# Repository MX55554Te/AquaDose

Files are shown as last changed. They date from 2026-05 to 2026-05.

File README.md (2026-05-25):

# AquaDose Release

AquaDose is an ESP32-based aquarium dosing controller with a native Android app and a local web interface. It controls up to 8 calibrated peristaltic pumps through external MOSFET driver circuits.

Open [README.html](README.html) in a browser for the full styled guide with screenshots, wiring notes, firmware instructions, Android app flow, troubleshooting, and safety notes. GitHub does not render Bootstrap HTML as a normal README page, so this markdown file is intentionally short.

# AquaDose wiring diagram

The simplified wiring diagram below shows the external MOSFET driver circuit used to control the peristaltic pumps from the ESP32.

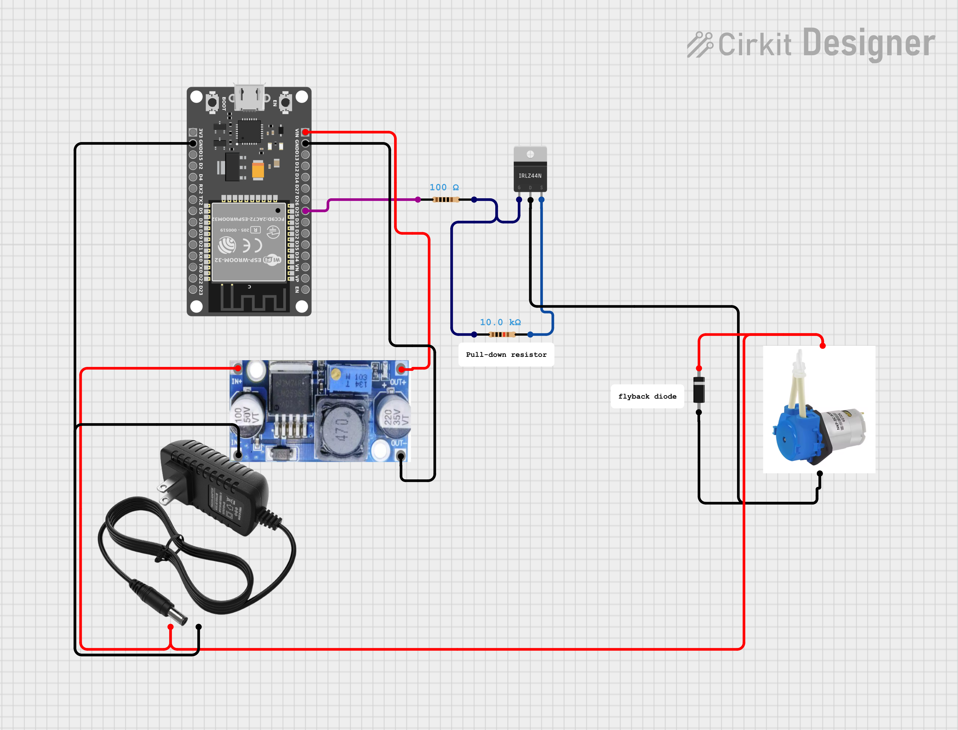
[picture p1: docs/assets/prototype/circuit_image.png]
AquaDose wiring diagram


## Prototype Photos

These photos show the current AquaDose prototype build, including the controller, wiring, pump layout, and enclosure progress.

<table>
  <tr>
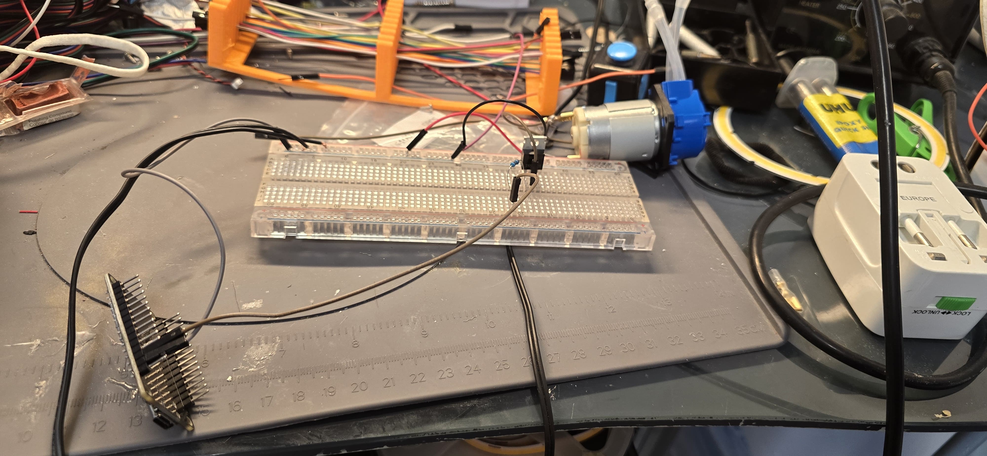
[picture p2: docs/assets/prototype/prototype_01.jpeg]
AquaDose prototype photo 1
    <td></td>
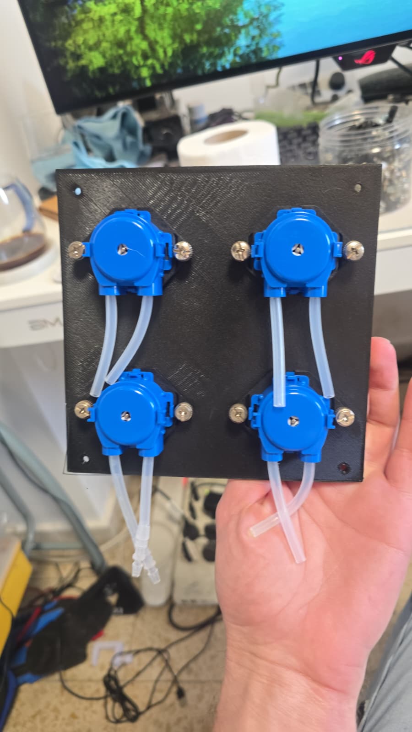
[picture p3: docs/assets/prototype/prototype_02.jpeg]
AquaDose prototype photo 2
    <td></td>
  <tr>
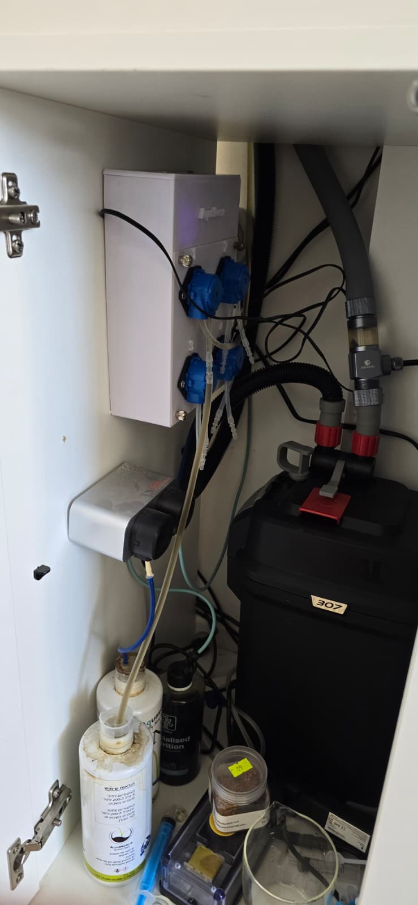
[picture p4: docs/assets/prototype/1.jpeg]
AquaDose prototype photo 1
    <td></td>
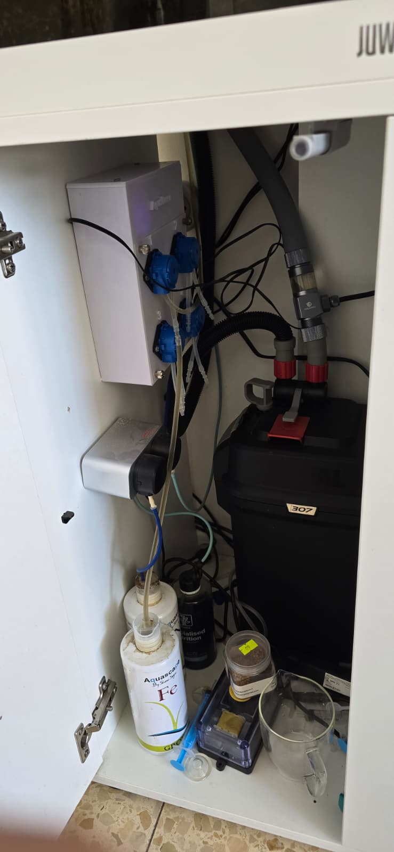
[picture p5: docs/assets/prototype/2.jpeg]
AquaDose prototype photo 2
    <td></td>
  <tr>
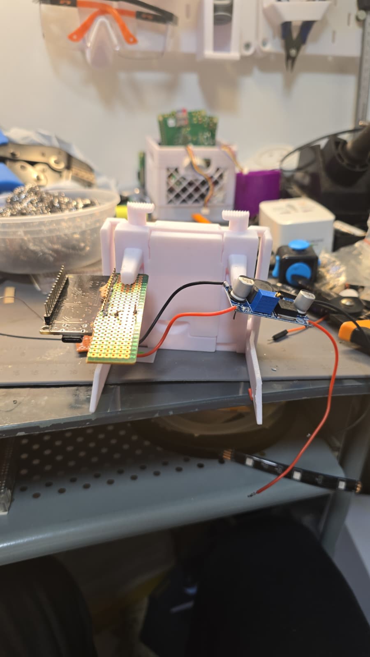
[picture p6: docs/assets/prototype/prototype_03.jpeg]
AquaDose prototype photo 3
    <td></td>
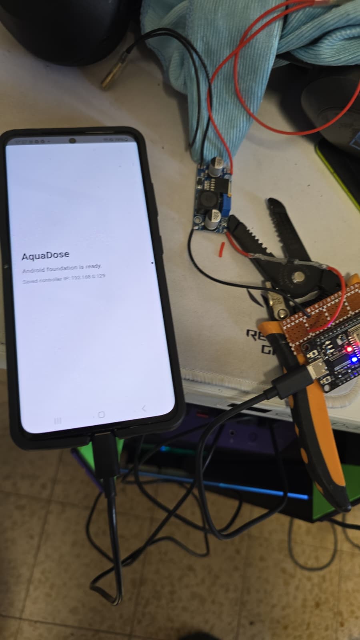
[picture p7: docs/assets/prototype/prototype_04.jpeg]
AquaDose prototype photo 4
    <td></td>
  </tr>
</table>

## Release Contents

```text
RELEASE/
  README.html
  README.md
  BUILD_NOTES.txt
  apk/
    AquaDose.apk
    SHA256SUMS.txt
  3d-model/
    AquaDose_Case.3mf
  source/
    android/
    arduino/
      AquaDose/
        AquaDose.ino
  docs/
    assets/
      screenshots/
      images/
      prototype/
        circuit_image.png
      3d-model/images/
      vendor/bootstrap/
```

Key files:

- Full styled guide: [README.html](README.html)
- Android APK: [apk/AquaDose.apk](apk/AquaDose.apk)
- Arduino firmware: [source/arduino/AquaDose/AquaDose.ino](source/arduino/AquaDose/AquaDose.ino)
- Android source: [source/android/](source/android/)
- Prototype photos: [docs/assets/prototype/](docs/assets/prototype/)
- Simplified schematic: [docs/assets/prototype/circuit_image.png](docs/assets/prototype/circuit_image.png)
- 3D model download: [3d-model/AquaDose_Case.3mf](3d-model/AquaDose_Case.3mf)

## Quick Install

1. Flash the ESP32 firmware from `source/arduino/AquaDose/AquaDose.ino`.
2. Join the AquaDose setup Wi-Fi network and open `http://192.168.4.1`.
3. Configure Wi-Fi and timezone.
4. Install `apk/AquaDose.apk`.
5. Connect the app to the controller IP.
6. Review the pump list, edit pump names if needed, and confirm GPIO mapping.
7. Prime and calibrate every pump with water.
8. Create schedules only after calibration. Enabled schedule doses must be between 0.1 and 999 ml.
9. Test a small manual dose with water before real aquarium dosing.

## APK

Verify it with:

```powershell
Get-FileHash -Algorithm SHA256 apk\AquaDose.apk
```

Expected SHA256:

```text
0a0208430aa682fba105903c86acb79431d913eea20efcb863a7b04eb061abcc
```

## Safety

Do not dose aquarium additives until each pump has been wired, primed, calibrated, and tested with water. Wrong wiring or wrong schedule values can harm aquarium livestock.

## Credits

Created by Or Araha  
LinkedIn: [https://www.linkedin.com/in/or-araha-05035aa5/](https://www.linkedin.com/in/or-araha-05035aa5/)

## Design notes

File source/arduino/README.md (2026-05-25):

# AquaDose ESP32 Firmware Source

Open `AquaDose/AquaDose.ino` in the Arduino IDE.

## Board And Libraries

The sketch targets ESP32 boards and uses standard ESP32 Arduino libraries:

- `WiFi.h`
- `WebServer.h`
- `Preferences.h`
- `time.h`
- ESP-IDF watchdog headers included with the ESP32 Arduino core

Install the ESP32 board support package in Arduino IDE before compiling.

## Default Hardware Mapping

The firmware defaults to 8 pumps on these GPIO pins:

| Pump | ESP32 GPIO |
| --- | --- |
| 1 | GPIO25 |
| 2 | GPIO26 |
| 3 | GPIO27 |
| 4 | GPIO14 |
| 5 | GPIO32 |
| 6 | GPIO33 |
| 7 | GPIO18 |
| 8 | GPIO19 |

Use a proper low-side logic-level N-MOSFET driver circuit for each pump channel: ESP32 GPIO through a 100 ohm series gate resistor, 10k ohm Gate-to-Source/GND pull-down resistor, flyback diode across the pump with stripe to +12V, external pump power supply, and shared common ground between ESP32 GND, buck GND, MOSFET Source, and pump supply negative.

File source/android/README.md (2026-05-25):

# AquaDose Android Source

This folder is a self-contained copy of the AquaDose Android app source.

## Build

From this directory:

```powershell
$env:JAVA_HOME='<path-to-jdk-17>'
$env:ANDROID_HOME='<path-to-android-sdk>'
$env:ANDROID_SDK_ROOT=$env:ANDROID_HOME
.\gradlew.bat :app:assembleDebug
```

The APK is generated at:

```text
app/build/outputs/apk/debug/app-debug.apk
```

Release signing is not configured in this source copy. Configure signing outside the repository before producing a production release build.

## Included Projects

- `app/`: Android app using Kotlin and Jetpack Compose.
- `android-api-contract/`: local API/model client dependency used by the app through Gradle composite build.

## Android Requirements

- Minimum SDK: 26
- Target SDK: 36
- Compile SDK: 36
- Java: 17

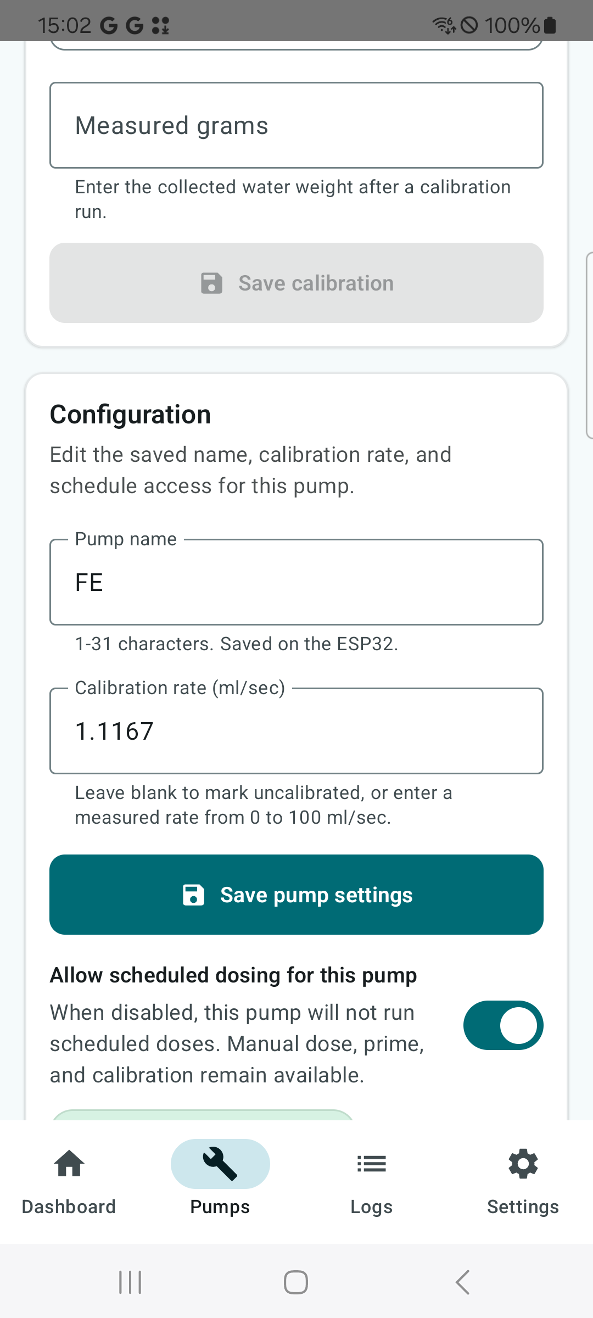
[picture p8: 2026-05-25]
docs/assets/screenshots/06-configuration.png

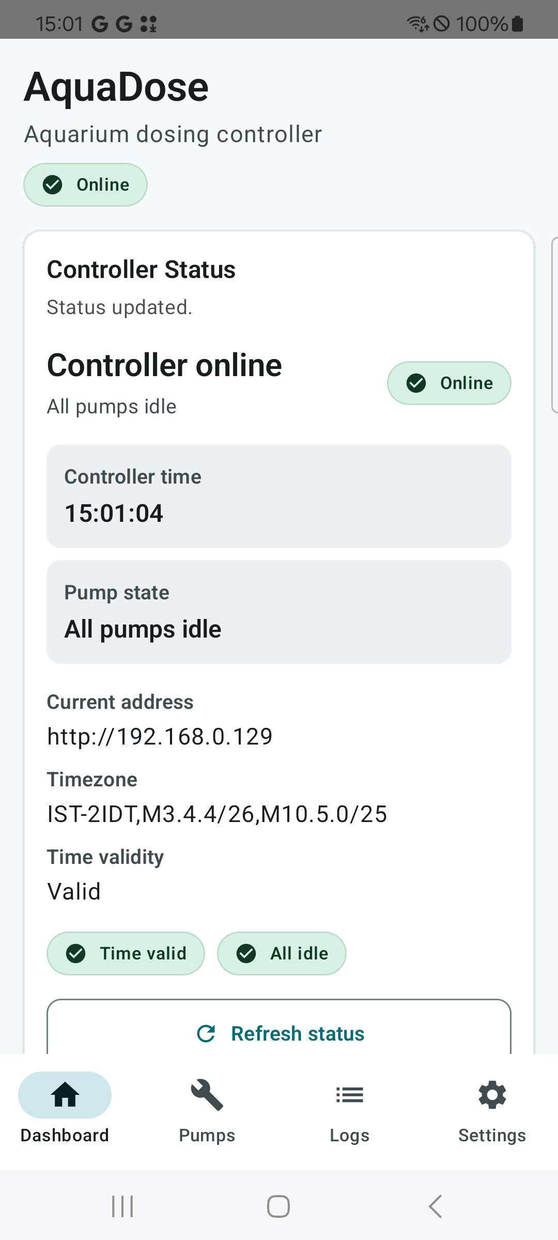
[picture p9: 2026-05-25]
docs/assets/screenshots/01-dashboard.png

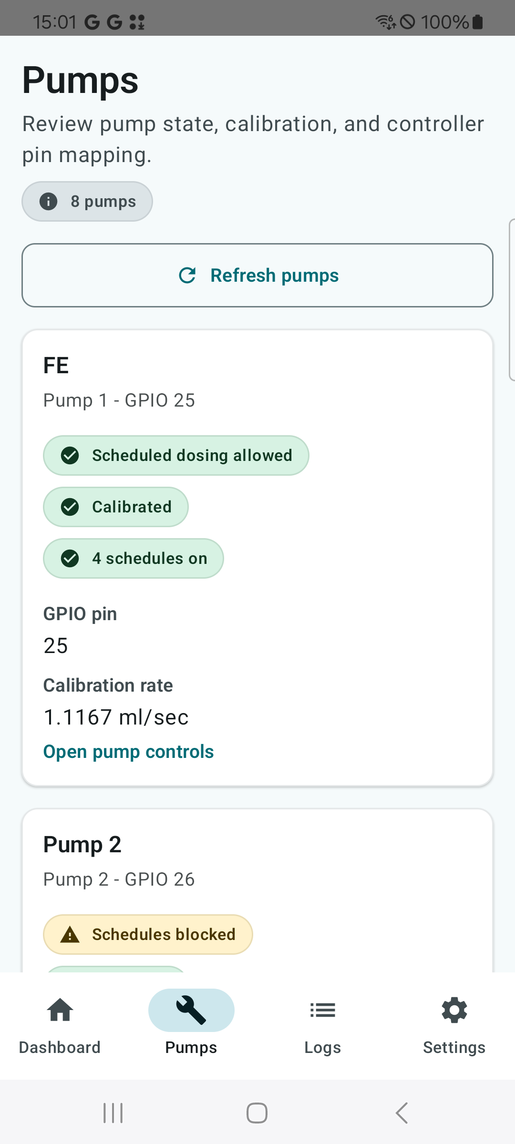
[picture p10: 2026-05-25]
docs/assets/screenshots/03-pump-card.png

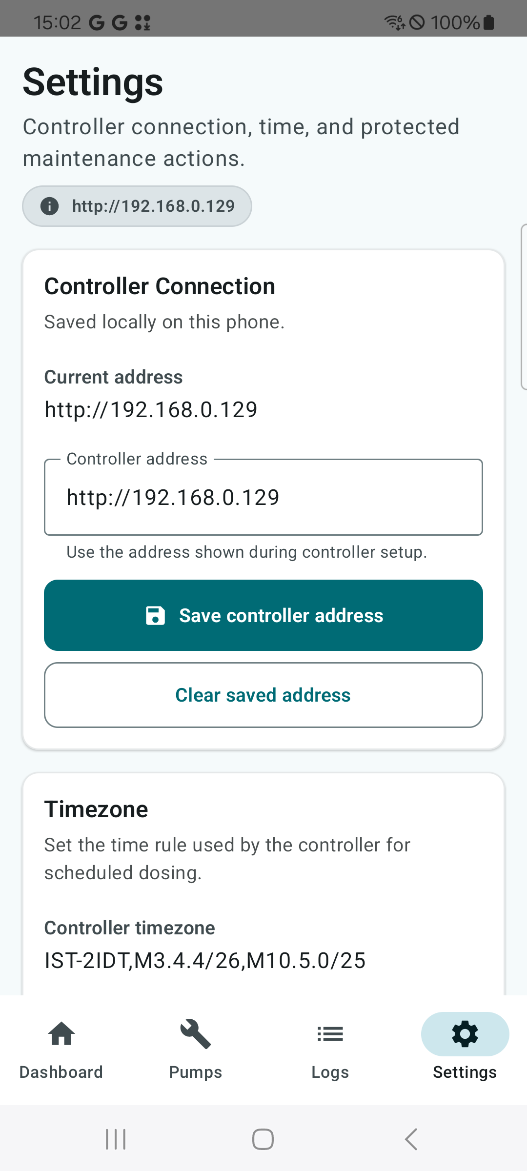
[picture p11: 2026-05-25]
docs/assets/screenshots/08-settings.png

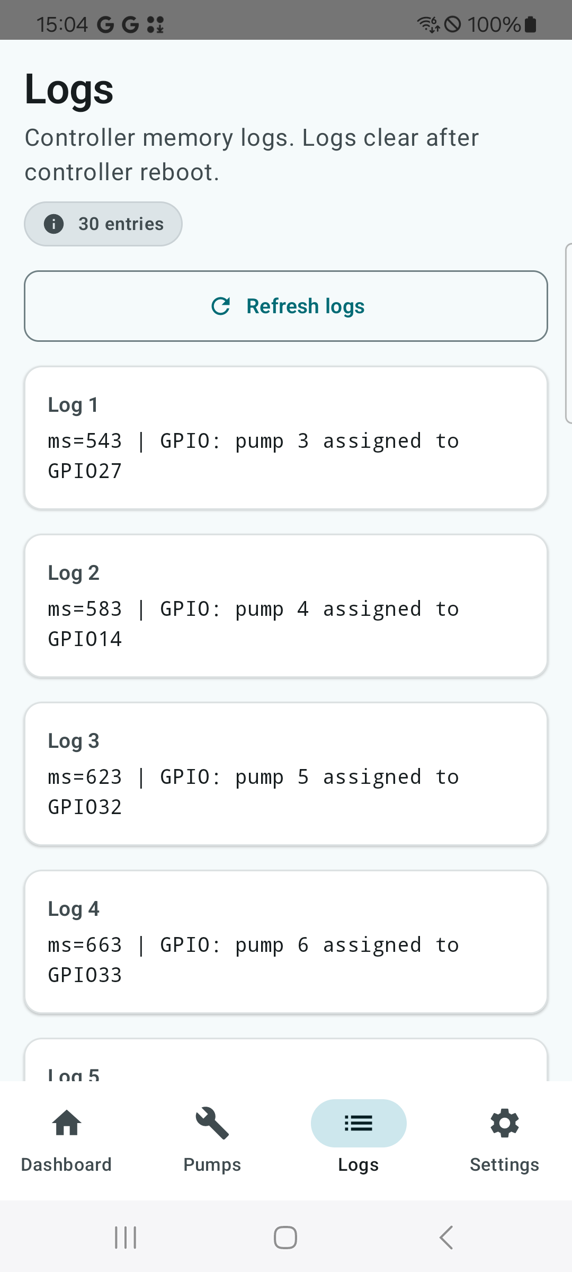
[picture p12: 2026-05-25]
docs/assets/screenshots/13-logs.png

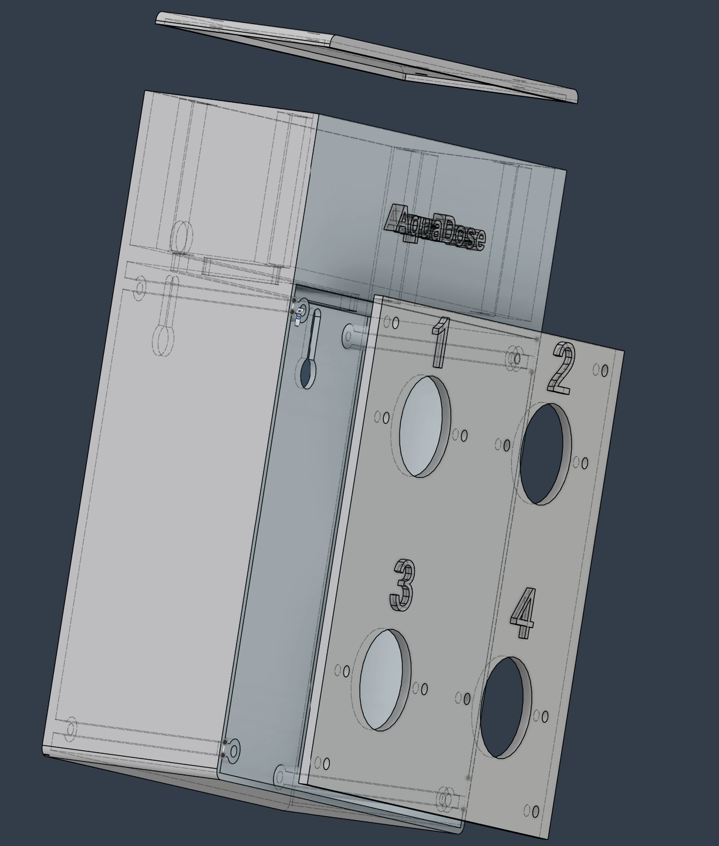
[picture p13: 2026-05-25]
docs/assets/3d-model/images/case_02.png

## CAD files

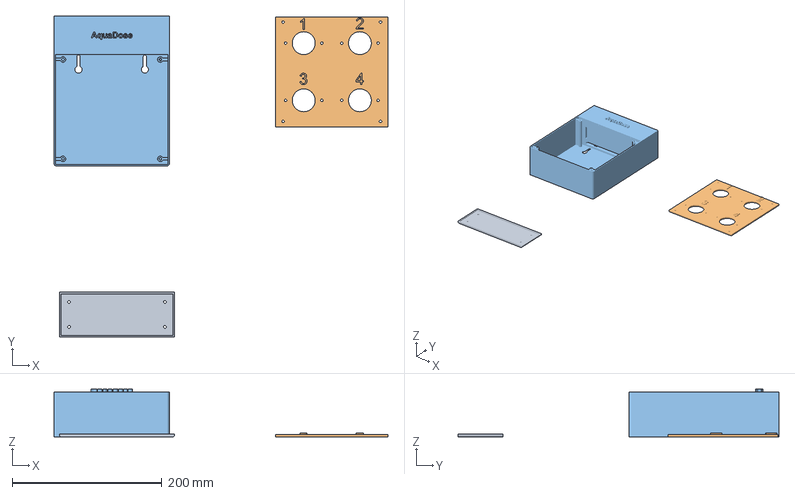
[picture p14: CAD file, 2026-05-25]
3d-model/AquaDose_Case.3mf
445.9 x 428.3 x 64.0 mm
Top_.stl
FRONT_Panel.stl
MAIN_Enclosure.stl

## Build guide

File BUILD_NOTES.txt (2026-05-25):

AquaDose RELEASE Build Notes
============================

Latest physical E2E QA continuation:
2026-05-15 23:18:00 +03:00

Scope:
Completed the previously blocked real pump activation checks after the controller outlets were confirmed safe for test-container/drain output. Factory reset and WiFi reset were not executed.

Physical/controller QA performed:
- ADB detected Samsung SM-G998B device R5CRB06R7TY and launched the Android app.
- ESP32 at http://192.168.0.129/ was reachable and the web UI loaded.
- Android manual dose flow was used for pumps 1-4 at 5 ml. /status showed only the intended runningPump for each run, then returned running=false and runningPump=-1.
- ESP32 web UI Manual Dose Now flow was used from the phone browser for pumps 1-4 at 5 ml. /status showed only the intended runningPump for each run, then returned running=false and runningPump=-1.
- Real near-future schedule activation used doses above the old 7 ml limit: Pump 1 = 9 ml, Pump 2 = 25 ml, Pump 3 = 100 ml, Pump 4 = 250.5 ml.
- Schedules persisted in /status before execution and logs recorded SCHEDULE match, DOSE start, and DOSE complete entries with the requested dose values. No value was clamped to 7 ml.
- Observed scheduled runtimes matched calculated runtimes: Pump 1 8.21s vs 8.06s, Pump 2 23.24s vs 23.08s, Pump 3 92.35s vs 92.31s, Pump 4 100.52s vs 100.20s.
- Pump 4 was temporarily set to 2.5000 ml/sec for the 250.5 ml scheduled test so the run stayed under the firmware's existing 120-second single-run guard; the pre-test Pump 4 rate of 0.0000 ml/sec was restored afterward.
- Restored the controller to the saved pre-test state after QA and confirmed /status reported running=false and runningPump=-1.
- Confirmed the Android app still loaded live controller status after restore.
- Confirmed the ESP32 web UI still loaded after restore.

Release artifact status:
- No Android or firmware source changes were required during this QA continuation.
- RELEASE/apk/AquaDose.apk remains the current rebuilt APK from the schedule dose range update.
- RELEASE/apk/SHA256SUMS.txt still matches RELEASE/apk/AquaDose.apk.

Latest schedule dose range update:
2026-05-15 22:18:32 +03:00

Purpose:
Removed the old Android scheduled-dose cap and replaced dose validation across the app/API contract/firmware source with the requested 0.1 to 999 ml range.

Implemented:
- Removed the Android-only scheduled-dose cap from Compose UI validation and MainViewModel save/toggle logic.
- Centralized dose limits in the shared android-api-contract validation constants.
- Updated manual dose and schedule validation copy to say: enter a valid dose between 0.1 and 999 ml.
- Updated Retrofit/query validation tests to cover 0.1, 1, 7, 25, 100, 250.5, and 999 ml.
- Updated ESP32 firmware source and the legacy firmware sketch copy to validate dose values from 0.1 to 999 ml.
- Updated README.html and README.md to remove the old scheduled-dose cap language.

Build/test results:
- android-api-contract test: passed.
- Android app assembleDebug: passed.
- Android app test: passed. App unit test tasks had no source tests.
- Android lint: passed with warnings only, mostly existing dependency-version and Compose style warnings.

Live ESP32 QA:
- ESP32 at http://192.168.0.129/ was reachable.
- Reversible /savePump persistence QA used Pump 2 with pump-level scheduled dosing kept blocked.
- Verified 0.1, 1, 7, 25, 100, 250.5, and 999 ml saved through /savePump, reloaded from /status, and matched the requested value.
- Restored Pump 2's original schedule afterward and confirmed no pump was running.

ADB UI QA:
- ADB detected device R5CRB06R7TY.
- Installed the rebuilt APK and launched com.aquadose.app/.MainActivity.
- Confirmed the app loaded live controller status from http://192.168.0.129/.
- Confirmed manual dose and schedule dose fields show the 0.1 to 999 ml validation copy.
- Confirmed the schedule dose field accepted 999 and 250.5 without UI clipping or validation error.
- Did not press Save schedule from the phone during UI QA; ESP32 persistence was verified with the reversible direct API test above.

Latest APK:
RELEASE/apk/AquaDose.apk
Size: 18,102,607 bytes
SHA256: 0a0208430aa682fba105903c86acb79431d913eea20efcb863a7b04eb061abcc

Previous Android UX/UI adaptive update:
2026-05-15 15:06:50 +03:00

Purpose:
Improved the native Android app UX/UI while preserving ESP32 HTTP endpoints, pump control behavior, calibration, scheduling, settings, maintenance, and logs.

Official UI guidance reviewed:
- Android Developers adaptive layouts.
- Android Developers window size classes.
- Android Developers adaptive navigation.
- Android Developers list-detail layout.
- Android Developers accessibility guidance.
- Material Design 3 adaptive layout guidance.

Implemented in Android:
- Added available-width adaptive behavior: compact, medium, and expanded width classes.
- Compact width keeps the single-column phone flow with bottom navigation.
- Medium/expanded width uses a navigation rail.
- Medium/expanded Pumps uses list-detail layout: pump list on the left and selected pump detail/actions on the right.
- Dashboard now shows the saved/current controller address when live status is loaded.
- Pump cards now make the saved pump name prominent and show GPIO, calibration status, schedule permission, and enabled schedule count.
- Schedule rows use a more responsive compact-vs-wide field layout while keeping dose validation visible and centralized.
- Pump action loading is more visible while waiting for controller confirmation.
- Schedule permission toggling no longer visually changes the saved pump state before the ESP32 confirms and /status refreshes.

Preserved behavior:
- ESP32 address normalization and HTTP communication.
- /status polling and refresh.
- /manual, /primeStart, /primeStop, /calRun, /calSave, /savePump, /saveTZ, /stop, /reset, and /factoryReset calls.
- Pump name editing and direct calibration-rate save.
- Full 8-slot schedule save payload preservation.
- Scheduled dose validation before save.
- Factory reset double-confirmation flow.

Build/test results:
- Android app assembleDebug: passed.
- Root Gradle test: passed. App unit test tasks had no source tests.
- android-api-contract test: passed.
- Gradle lint: passed.
- A clean rebuild attempt hit a Windows file lock in Gradle's lint cache; Gradle daemon was stopped and a fresh assembleDebug completed successfully.

Device QA:
- ADB available: Android Debug Bridge 37.0.0.
- Connected device: R5CRB06R7TY.
- Installed fresh debug APK with adb install -r.
- Launched com.aquadose.app/.MainActivity.
- Confirmed app loaded live ESP32 status from http://192.168.0.129/.
- Confirmed dashboard showed Online, current controller address, controller time, timezone, and idle pump state.
- Confirmed pump list loaded 8 pumps and showed pump name, GPIO, calibration status, schedule permission, and enabled schedule count.
- Confirmed pump detail, manual dose UI, prime/stop UI, calibration UI, configuration UI, schedule editor, settings, maintenance, factory reset confirmations, and logs were present after install.
- Confirmed landscape on the connected phone uses navigation rail and list-detail pump layout with live pump data.
- Factory reset dialogs were opened for screenshot/flow verification and canceled; factory reset was not executed.
- Hardware-moving actions were not confirmed during this QA pass because the physical aquarium/tubing/container state could not be verified from the tool session.

Screenshots:
- Updated docs/assets/screenshots/*.png from real ADB screencaps on the connected phone.
- Factory reset screenshots show confirmation dialogs only and did not execute reset.

Latest APK:
RELEASE/apk/AquaDose.apk
Size: 18,102,619 bytes
SHA256: 7ba97f296c84efca912c69a411b479340376784f235d8a3d497ee806540f5a6f

Release documentation update:
- README.html updated for adaptive Android navigation/layout behavior, current screenshots, pump list/detail, configuration, calibration, manual dose, prime/stop prime, scheduled dosing validation, logs, reconnect/settings, factory reset flow, troubleshooting, and safe testing outside the aquarium.
- README.md updated with the new APK checksum.

Latest Android parity update:
2026-05-15 14:41:15 +03:00

Purpose:
Compared the live ESP32 web UI at http://192.168.0.129/ with the Android source and firmware/API contract, then added Android support for confirmed missing pump-name editing and related confirmed pump configuration behavior.

Implemented in Android:
- Pump name edit/save in the pump Configuration section using the firmware /savePump endpoint.
- Pump settings save refreshes /status and displays the controller-confirmed saved pump name.
- Direct calibration rate edit/save through /savePump while preserving schedules.
- Android-side pump name validation: trim whitespace, reject empty names, and limit names to 31 characters to match firmware storage.
- Android schedule validation is performed before sending schedule changes.
- Schedule editor now marks unsaved row edits clearly and resyncs draft rows after a confirmed save.

Bug found and fixed:
- After a valid schedule save, the phone UI initially kept showing the row as pending even though the ESP32 had accepted the save. MainViewModel now refreshes and resyncs schedule drafts after saving schedules.

Build/test results:
- android-api-contract tests: passed.
- Android app assembleDebug: passed.
- app:testDebugUnitTest: no test sources.

Device QA:
- ADB available.
- Installed the fresh debug APK on Samsung SM-G998B, adb serial R5CRB06R7TY.
- Launched com.aquadose.app/.MainActivity.
- Connected to the ESP32 at http://192.168.0.129/.
- Verified pump data loads, pump name save persists after app force-stop/relaunch, schedule validation blocks invalid enabled rows before sending, a valid schedule row saves/reloads from ESP32, row disable restores, and pump-level scheduled dosing toggles on/off with no enabled rows.
- Verified Logs screen, Reset Wi-Fi confirmation, factory reset first confirmation, and Start Prime confirmation without confirming hardware-moving or reset actions.
- No manual dose, prime start, 60-second calibration run, Wi-Fi reset, or factory reset command was confirmed during QA.

Latest APK:
RELEASE/apk/AquaDose.apk
Size: 18,638,161 bytes
SHA256: 8f07265184178c3f89e31c53cf85e9c99584e7bfeba1126e933f651ba2472c3f

Release documentation update:
- README.html updated for Android connection, pump list, pump name editing, calibration, manual dose, prime/stop prime, scheduled dosing validation, uncalibrated 0.0 default behavior, reset/reconnect flows, troubleshooting, and safe water testing.
- README.md updated with the new APK checksum and Android schedule validation note.

Build date/time:
2026-05-14 21:50:30 +03:00

Android build variant:
debug

Reason:
Release signing is not configured in the Android Gradle project. A debug APK was built and copied as the installable release artifact.

APK path:
RELEASE/apk/AquaDose.apk

APK size:
18,558,017 bytes

APK SHA256:
f4366d08cae9ec4018483442faf4a79577db71d5c1921e210ce4627bc125f803

APK install test:
Passed. The APK was installed from RELEASE/apk/AquaDose.apk onto the connected Android phone with adb install -r.

Connected Android device:
Samsung SM-G998B, adb serial R5CRB06R7TY.

Phone screenshots:
Captured from the connected phone using ADB screencap and adb pull.

Screenshot notes:
- App screenshots were captured from the installed AquaDose APK.
- The factory reset screenshot shows the confirmation dialog only. Factory reset was not confirmed.
- The reconnect/setup screenshot uses the app's built-in setup address flow for http://192.168.4.1. No ESP32 reset was performed for that screenshot.
- Android app local preferences were restored to the default empty state after the reconnect/setup screenshot.

Failures or limitations:
- A production release APK/AAB was not produced because no release signing configuration exists.
- The included APK is debug signed.
- The firmware source currently serves its own web UI with Bootstrap and Bootstrap Icons referenced from CDN URLs. RELEASE/README.html itself is self-contained and uses local Bootstrap files.
- Arduino firmware was copied and inspected, but not compiled in this release pass.
- The project directory was not a Git working tree in this workspace, so validation used filesystem checks rather than git status.

Commands used:

Inspect project:
  Get-ChildItem -Force
  rg --files -g '!RELEASE/**' -g '!**/.gradle/**' -g '!**/build/**' -g '!**/.git/**'

Build Android debug APK:
  $env:JAVA_HOME='<Android Studio bundled JBR>'
  $env:ANDROID_HOME='%LOCALAPPDATA%\Android\Sdk'
  $env:ANDROID_SDK_ROOT=$env:ANDROID_HOME
  .\gradlew.bat :app:assembleDebug

Check device:
  %LOCALAPPDATA%\Android\Sdk\platform-tools\adb.exe devices -l

Install release APK:
  %LOCALAPPDATA%\Android\Sdk\platform-tools\adb.exe install -r RELEASE\apk\AquaDose.apk

Capture app screenshots:
  %LOCALAPPDATA%\Android\Sdk\platform-tools\adb.exe shell am start -n com.aquadose.app/.MainActivity
  %LOCALAPPDATA%\Android\Sdk\platform-tools\adb.exe shell screencap -p /sdcard/<screenshot>.png
  %LOCALAPPDATA%\Android\Sdk\platform-tools\adb.exe pull /sdcard/<screenshot>.png RELEASE\docs\assets\screenshots\

Create APK checksum:
  Get-FileHash -Algorithm SHA256 RELEASE\apk\AquaDose.apk

Bootstrap assets:
  Downloaded Bootstrap 5.3.3 CSS, Bootstrap 5.3.3 bundle JS, and Bootstrap LICENSE.txt into RELEASE/docs/assets/vendor/bootstrap/.

Wiring documentation update:
  Replaced the previous README.html wiring diagram images with deterministic local SVG diagrams:
    RELEASE/docs/assets/images/single-pump-channel.svg
    RELEASE/docs/assets/images/multi-channel-repeat.svg
  Corrected the documented low-side N-MOSFET pump wiring.
  Added the MOSFET Gate-to-Source/Common GND 10k ohm pull-down resistor to the documentation and wiring table.
  Clarified that the 100 ohm gate resistor is a series resistor and does not replace the pull-down resistor.
  Added the ESP32 3.3V logic-level MOSFET selection warning.

Arduino release source rename:
  Renamed the release sketch folder to RELEASE/source/arduino/AquaDose/.
  Renamed the main sketch file to RELEASE/source/arduino/AquaDose/AquaDose.ino.
  Updated release documentation to use the Arduino IDE-compatible AquaDose/AquaDose.ino path.

Prototype and 3D model documentation update:
  Update date/time: 2026-05-15 00:33:15 +03:00
  Copied 4 real prototype photos into RELEASE/docs/assets/prototype/.
  Copied the simplified schematic to RELEASE/docs/assets/prototype/circuit_image.png.
  Added the simplified schematic to README.html as a beginner-friendly overview while keeping the SVG schematic as the authoritative wiring reference.
  Visual schematic inspection did not find a mismatch with the documented low-side MOSFET wiring. README.html includes a visible note to verify the chosen MOSFET is fully enhanced at 3.3V ESP32 gate drive.
  Copied the printable 3D model file to RELEASE/3d-model/AquaDose_Case.3mf.
  Copied 4 3D model images into RELEASE/docs/assets/3d-model/images/.
  Added README.html sections for real prototype photos, the 3D printed enclosure, and credits.
  Added credit and LinkedIn link to README.html and README.md.
  Skipped files or problems: none found.

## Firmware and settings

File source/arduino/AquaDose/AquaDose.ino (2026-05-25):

/*
 * AquaDose
 *
 * This firmware implements a multiâ€‘channel dosing system for aquarium maintenance.
 * It supports up to PUMP_COUNT peristaltic pumps, configurable dosing
 * schedules, priming and calibration routines, and an onboard web
 * interface.  The interface is served over HTTP using the builtâ€‘in
 * WebServer library and styled using Bootstrap loaded from a CDN.  Users
 * can configure WiFi credentials, timezone settings, pump calibration,
 * dosing schedules and names via their browser.
 *
 * Features
 * --------
 *  - SoftAP setup mode: on first boot or after a WiFi reset the
 *    controller exposes an access point (AP) so the user can enter
 *    network credentials and select a timezone.  Credentials and
 *    configuration are stored in the nonâ€‘volatile NVS using the
 *    Preferences library.
 *  - Nonâ€‘blocking pump control: pumps run in the background without
 *    blocking the web server or scheduler.  A global run state is used
 *    to time pump activations and provide an emergency stop.
 *  - Calibration: users can prime a pump until fluid flows and then
 *    run a 60Â second calibration cycle.  After measuring the volume
 *    dispensed (in grams for water), they enter the value which is
 *    automatically converted to ml/sec and stored.
 *  - Dosing schedules: each pump supports a configurable array of
 *    schedule slots.  Each slot defines a time of day and a volume
 *    (ml) to dispense.  The controller ensures a schedule runs no
 *    more than once per day by tracking the last run date.
 *  - History log: recent pump activations are recorded with a
 *    timestamp, pump index, volume and reason.  The log is exposed via
 *    the web interface.
 *  - Timezone: the user can select from a list of common POSIX
 *    timezone strings.  The selected value is applied at runtime
 *    using tzset() and persisted in NVS.
 *  - Factory reset: a web route allows clearing saved WiFi credentials
 *    and timezone, forcing the unit back into setup mode.  Holding the
 *    BOOT pin (GPIO0) during startup for 5Â seconds also resets the
 *    configuration.
 *
 * Wiring
 * ------
 *  Connect each pump's negative lead to the drain of the MOSFET,
 *  connect the source to the common ground and the gate to the
 *  specified pumpPins[] element via a 100Â Î© resistor.  Always fit a
 *  flyback diode across the pump terminals (stripe on the diode to
 *  positive supply).
 *
 *  Ensure the ESP32's ground is tied to the power supply ground.  Use
 *  a 12Â V supply with adequate current rating and a buck converter to
 *  generate 5Â V for the ESP32.
 */

#include <WiFi.h>
#include <WebServer.h>
#include <Preferences.h>
#include <time.h>
#include <esp_task_wdt.h>
#include <esp_idf_version.h>
#include <freertos/FreeRTOS.h>
#include <stdarg.h>
#include <math.h>

// -----------------------------------------------------------------------------
// Configuration constants
// Adjust these values to match your hardware setup.
// -----------------------------------------------------------------------------

// Number of peristaltic pumps connected to the controller.  Up to 8
// pumps are supported but memory consumption increases with higher
// values.
#ifndef PUMP_COUNT
#define PUMP_COUNT 8
#endif

#if PUMP_COUNT < 1 || PUMP_COUNT > 8
#error "PUMP_COUNT must be between 1 and 8"
#endif

// Maximum number of dosing schedules per pump.  Each schedule can run
// once per day.  Increase this value to allow more daily dosings but
// note that web interface complexity increases accordingly.
#ifndef MAX_SCHEDULES
#define MAX_SCHEDULES 8
#endif

const float MIN_DOSE_ML = 0.1f;
const float MAX_DOSE_ML = 999.0f;

// Number of recent log entries kept in RAM for the web page.  These are
// intentionally not saved to NVS to avoid wearing flash memory.
#ifndef LOG_COUNT
#define LOG_COUNT 30
#endif

// GPIO pins assigned to pump MOSFET gates.  Change this array to
// reflect your wiring.  Avoid using pins required for boot mode
// selection (e.g. GPIO0, GPIO2, GPIO15) if possible.  Pins must be
// output capable.
const uint8_t PUMP_PINS[] = { 25, 26, 27, 14, 32, 33, 18, 19 };

static_assert(PUMP_COUNT <= (sizeof(PUMP_PINS) / sizeof(PUMP_PINS[0])),
              "PUMP_COUNT is greater than the number of configured PUMP_PINS");

// Status LED.  Many ESP32 dev boards use GPIO2 for the onboard LED.
// Set STATUS_LED_PIN to another GPIO if your board uses a different LED pin.
#ifndef STATUS_LED_PIN
#ifdef LED_BUILTIN
#define STATUS_LED_PIN LED_BUILTIN
#else
#define STATUS_LED_PIN 2
#endif
#endif
const bool STATUS_LED_ACTIVE_HIGH = true;
const unsigned long STATUS_LED_BLINK_MS = 500;

// SoftAP configuration when entering setup mode.  The SSID suffix is
// automatically appended with a unique number based on the chip ID.
const char *SOFT_AP_SSID_BASE = "AquaDose";
const char *SOFT_AP_PASSWORD = "12345678"; // must be at least 8 characters

// Name of the NVS namespace used for storing persistent settings.
const char *NVS_NAMESPACE = "dosing_cfg";

// Timeout in milliseconds for WiFi connection attempts before
// reverting to AP mode on failure.
const unsigned long WIFI_CONNECT_TIMEOUT_MS = 20000;

// Serial Monitor baud rate.
const unsigned long SERIAL_BAUD = 115200;

// NTP servers used after STA WiFi connects.  Time is required for
// schedules and readable log timestamps.
const char *NTP_SERVER_1 = "pool.ntp.org";
const char *NTP_SERVER_2 = "time.nist.gov";

// Timeout for priming a pump in seconds.  Priming stops
// automatically after this period to prevent accidental long run.
const int PRIME_TIMEOUT_SEC = 120;

// Check schedules several times per minute so a schedule edited close
// to its target minute is not missed.
const unsigned long SCHEDULE_CHECK_INTERVAL_MS = 5000;

// Watchdog timeout (in seconds).  We reset the watchdog regularly to
// avoid reboots when the web server blocks for too long.  Adjust
// according to your expected maximum blocking duration.
const int WATCHDOG_TIMEOUT_SEC = 10;

// -----------------------------------------------------------------------------
// Data structures
// -----------------------------------------------------------------------------

// A single schedule specifying a time and dose volume for a pump.  A
// schedule runs once per day at its configured time, provided the
// pump is enabled and the schedule is enabled.
struct ScheduleItem {
  bool enabled;
  int hour;
  int minute;
  float ml;
  int lastRunDay;
};

// Configuration for a single pump.
struct PumpConfig {
  bool enabled;        // whether scheduling is active for this pump
  char name[32];       // user defined pump name
  float mlPerSec;      // calibration value (ml per second)
  ScheduleItem schedules[MAX_SCHEDULES];
};

// Structure tracking the current running pump state.  Only one pump
// runs at a time to prevent overloading the power supply and to
// simplify hardware design.
struct RunState {
  bool running;        // true if a pump is currently running
  int pump;            // index of running pump (0â€“PUMP_COUNT-1) or -1
  unsigned long stopAt; // time to stop pump (millis).  0 means indefinite
  float ml;            // dose volume for log (or -1 for prime)
  char reason[16];     // reason for log entry (e.g. "schedule", "manual", "prime", "calib")
};

// Global variables

Preferences prefs;
WebServer server(80);

// Pump configuration array
PumpConfig pumps[PUMP_COUNT];

// Run state
RunState runState = {false, -1, 0, 0.0f, {0}};

// Timestamp for the start of an indefinite prime.  When a pump is
// primed indefinitely (stopAt == 0) we use this to enforce a safety
// timeout.  It is reset whenever a new prime starts or stops.
unsigned long primeStartTime = 0;

// Recent pump actions for the web page.  RAM only; cleared on reboot.
String ramLogs[LOG_COUNT];
int ramLogNext = 0;

// WiFi credentials and timezone (POSIX format)
String wifiSSID;
String wifiPass;
String tzString;
bool wifiConfigured = false;
bool wifiPendingValidation = false;
bool setupMode = false;

// -----------------------------------------------------------------------------
// Utility functions
// -----------------------------------------------------------------------------

void copyCString(char *dest, size_t destSize, const char *src) {
  if (destSize == 0) return;
  if (src == nullptr) src = "";
  strncpy(dest, src, destSize - 1);
  dest[destSize - 1] = '\0';
}

String jsonEscape(const String &input) {
  String out;
  out.reserve(input.length() + 8);
  for (size_t i = 0; i < input.length(); i++) {
    char c = input.charAt(i);
    uint8_t b = (uint8_t)c;
    switch (c) {
      case '\"': out += "\\\""; break;
      case '\\': out += "\\\\"; break;
      case '\b': out += "\\b"; break;
      case '\f': out += "\\f"; break;
      case '\n': out += "\\n"; break;
      case '\r': out += "\\r"; break;
      case '\t': out += "\\t"; break;
      default:
        if (b < 0x20) {
          char buf[7];
          snprintf(buf, sizeof(buf), "\\u%04x", b);
          out += buf;
        } else {
          out += c;
        }
        break;
    }
  }
  return out;
}

bool readPumpArg(int &pumpIndex) {
  if (!server.hasArg("p")) return false;
  String value = server.arg("p");
  if (value.length() == 0) return false;
  for (size_t i = 0; i < value.length(); i++) {
    if (!isDigit(value.charAt(i))) return false;
  }
  pumpIndex = value.toInt();
  return pumpIndex >= 0 && pumpIndex < PUMP_COUNT;
}

bool readIntArgStrict(const String &name, int &out) {
  if (!server.hasArg(name)) return false;
  String value = server.arg(name);
  value.trim();
  if (value.length() == 0) return false;
  int start = 0;
  if (value.charAt(0) == '-' || value.charAt(0) == '+') {
    if (value.length() == 1) return false;
    start = 1;
  }
  for (int i = start; i < value.length(); i++) {
    if (!isDigit(value.charAt(i))) return false;
  }
  out = value.toInt();
  return true;
}

bool readFloatArgStrict(const String &name, float &out) {
  if (!server.hasArg(name)) return false;
  String value = server.arg(name);
  value.trim();
  if (value.length() == 0) return false;
  int start = 0;
  bool sawDigit = false;
  bool sawDot = false;
  if (value.charAt(0) == '-' || value.charAt(0) == '+') {
    if (value.length() == 1) return false;
    start = 1;
  }
  for (int i = start; i < value.length(); i++) {
    char c = value.charAt(i);
    if (isDigit(c)) {
      sawDigit = true;
      continue;
    }
    if (c == '.' && !sawDot) {
      sawDot = true;
      continue;
    }
    return false;
  }
  if (!sawDigit) return false;
  out = value.toFloat();
  return true;
}

int clampInt(int value, int minValue, int maxValue) {
  if (value < minValue) return minValue;
  if (value > maxValue) return maxValue;
  return value;
}

void setStatusLed(bool on) {
  digitalWrite(STATUS_LED_PIN, (on == STATUS_LED_ACTIVE_HIGH) ? HIGH : LOW);
}

void appendRamLogLine(const char *line) {
  ramLogs[ramLogNext] = line;
  ramLogNext = (ramLogNext + 1) % LOG_COUNT;
}

void serialLogf(const char *format, ...) {
  char message[192];
  va_list args;
  va_start(args, format);
  vsnprintf(message, sizeof(message), format, args);
  va_end(args);

  Serial.print("[");
  struct tm t;
  if (getLocalTime(&t, 10)) {
    char timestamp[24];
    snprintf(timestamp, sizeof(timestamp), "%04d-%02d-%02d %02d:%02d:%02d",
             t.tm_year + 1900, t.tm_mon + 1, t.tm_mday,
             t.tm_hour, t.tm_min, t.tm_sec);
    Serial.print(timestamp);
  } else {
    Serial.print("ms=");
    Serial.print(millis());
  }
  Serial.print("] ");
  Serial.println(message);

  char line[240];
  struct tm logTime;
  if (getLocalTime(&logTime, 10)) {
    snprintf(line, sizeof(line), "%04d-%02d-%02d %02d:%02d:%02d | %s",
             logTime.tm_year + 1900, logTime.tm_mon + 1, logTime.tm_mday,
             logTime.tm_hour, logTime.tm_min, logTime.tm_sec, message);
  } else {
    snprintf(line, sizeof(line), "ms=%lu | %s", millis(), message);
  }
  appendRamLogLine(line);
}

/*
 * Add a recent log entry for the web page.  This is RAM only and is
 * intentionally not saved to NVS, because pump activity can create many
 * writes and NVS flash has limited write endurance.
 */
void addLog(int pumpIndex, float ml, const char *reason) {
  // Build timestamp string
  char timestamp[25];
  struct tm t;
  if (getLocalTime(&t)) {
    snprintf(timestamp, sizeof(timestamp), "%04d-%02d-%02d %02d:%02d",
             t.tm_year + 1900, t.tm_mon + 1, t.tm_mday, t.tm_hour, t.tm_min);
  } else {
    copyCString(timestamp, sizeof(timestamp), "no-time");
  }
  // Build log line
  char line[96];
  char mlStr[16];
  if (ml < 0) {
    // prime or indefinite operation, mark volume as "--"
    copyCString(mlStr, sizeof(mlStr), "--");
  } else {
    snprintf(mlStr, sizeof(mlStr), "%.2f", ml);
  }
  snprintf(line, sizeof(line), "%s | Pump %d | %s ml | %s", timestamp, pumpIndex + 1, mlStr, reason);
  appendRamLogLine(line);
}

/*
 * Load WiFi credentials and timezone from NVS.  If credentials are
 * missing, wifiConfigured remains false and the system enters setup
 * mode.  Timezone is set to a default (Asia/Jerusalem) if missing.
 */
void loadWifiAndTZ() {
  prefs.begin(NVS_NAMESPACE, true);
  wifiSSID = prefs.getString("wifi_ssid", "");
  wifiPass = prefs.getString("wifi_pass", "");
  tzString = prefs.getString("tz", "IST-2IDT,M3.4.4/26,M10.5.0/25");
  wifiPendingValidation = prefs.getBool("wifi_pending", false);
  prefs.end();
  wifiConfigured = (wifiSSID.length() > 0 && wifiPass.length() > 0);
  if (!wifiConfigured) {
    setupMode = true;
  }
  // Apply timezone
  setenv("TZ", tzString.c_str(), 1);
  tzset();
}

/*
 * Save WiFi credentials and timezone to NVS.  Called after user
 * submits credentials via the setup web page.  After saving, the
 * device will reboot to apply settings.
 */
void saveWifiAndTZ(const String &ssid, const String &pass, const String &tz) {
  prefs.begin(NVS_NAMESPACE, false);
  prefs.putString("wifi_ssid", ssid);
  prefs.putString("wifi_pass", pass);
  prefs.putString("tz", tz);
  prefs.putBool("wifi_pending", true);
  prefs.end();
}

void markWifiSettingsValidated() {
  prefs.begin(NVS_NAMESPACE, false);
  prefs.putBool("wifi_pending", false);
  prefs.end();
  wifiPendingValidation = false;
}

void discardPendingWifiSettings() {
  serialLogf("WiFi: first connection failed, clearing pending credentials from memory");
  prefs.begin(NVS_NAMESPACE, false);
  prefs.remove("wifi_ssid");
  prefs.remove("wifi_pass");
  prefs.remove("wifi_pending");
  prefs.end();
  wifiSSID = "";
  wifiPass = "";
  wifiConfigured = false;
  wifiPendingValidation = false;
  setupMode = true;
  WiFi.disconnect(true, true);
}

/*
 * Clear WiFi credentials and timezone from NVS.  This will cause
 * setup mode to be entered on next boot.
 */
void resetWifiSettings() {
  prefs.begin(NVS_NAMESPACE, false);
  prefs.remove("wifi_ssid");
  prefs.remove("wifi_pass");
  prefs.remove("wifi_pending");
  prefs.remove("tz");
  prefs.end();
  wifiSSID = "";
  wifiPass = "";
  wifiConfigured = false;
  wifiPendingValidation = false;
  setupMode = true;
}

/*
 * Clear every stored AquaDose setting from this firmware namespace.
 * This removes WiFi, timezone, pump names, calibration rates, schedules,
 * and schedule last-run markers.  Runtime RAM logs clear naturally on reboot.
 */
void factoryResetSettings() {
  serialLogf("Factory reset: clearing all saved AquaDose settings");
  stopAllPumps();
  prefs.begin(NVS_NAMESPACE, false);
  prefs.clear();
  prefs.end();
  wifiSSID = "";
  wifiPass = "";
  tzString = "IST-2IDT,M3.4.4/26,M10.5.0/25";
  wifiConfigured = false;
  wifiPendingValidation = false;
  setupMode = true;
  WiFi.disconnect(true, true);
}

/*
 * Load pump configuration from NVS into the pumps[] array.  If
 * configuration is missing, defaults are applied.  Each pump's
 * settings are stored under keys derived from the pump index.
 */
void loadPumpConfig() {
  prefs.begin(NVS_NAMESPACE, true);
  for (int p = 0; p < PUMP_COUNT; p++) {
    String base = "p" + String(p) + "_";
    pumps[p].enabled = prefs.getBool((base + "en").c_str(), false);
    pumps[p].mlPerSec = prefs.getFloat((base + "rate").c_str(), 0.0f);
    String defaultName = "Pump " + String(p + 1);
    String savedName = prefs.getString((base + "name").c_str(), defaultName);
    savedName.toCharArray(pumps[p].name, sizeof(pumps[p].name));
    for (int s = 0; s < MAX_SCHEDULES; s++) {
      String sb = base + "s" + String(s) + "_";
      pumps[p].schedules[s].enabled = prefs.getBool((sb + "en").c_str(), false);
      pumps[p].schedules[s].hour = prefs.getInt((sb + "h").c_str(), 12);
      pumps[p].schedules[s].minute = prefs.getInt((sb + "m").c_str(), 0);
      pumps[p].schedules[s].ml = prefs.getFloat((sb + "ml").c_str(), 1.0f);
      pumps[p].schedules[s].lastRunDay = prefs.getInt((sb + "last").c_str(), -1);
    }
  }
  prefs.end();
}

/*
 * Save configuration for a single pump to NVS.  Called after the
 * user updates pump settings via the web interface.
 */
void savePumpConfig(int p) {
  prefs.begin(NVS_NAMESPACE, false);
  String base = "p" + String(p) + "_";
  prefs.putBool((base + "en").c_str(), pumps[p].enabled);
  prefs.putFloat((base + "rate").c_str(), pumps[p].mlPerSec);
  prefs.putString((base + "name").c_str(), String(pumps[p].name));
  for (int s = 0; s < MAX_SCHEDULES; s++) {
    String sb = base + "s" + String(s) + "_";
    prefs.putBool((sb + "en").c_str(), pumps[p].schedules[s].enabled);
    prefs.putInt((sb + "h").c_str(), pumps[p].schedules[s].hour);
    prefs.putInt((sb + "m").c_str(), pumps[p].schedules[s].minute);
    prefs.putFloat((sb + "ml").c_str(), pumps[p].schedules[s].ml);
    prefs.putInt((sb + "last").c_str(), pumps[p].schedules[s].lastRunDay);
  }
  prefs.end();
}

/*
 * Stop any running pump immediately.  Called on emergency stop or
 * prime stop.  Also resets runState.
 */
void stopAllPumps() {
  bool wasRunning = runState.running;
  int stoppedPump = runState.pump;
  char stoppedReason[sizeof(runState.reason)];
  copyCString(stoppedReason, sizeof(stoppedReason), runState.reason);

  for (int i = 0; i < PUMP_COUNT; i++) {
    digitalWrite(PUMP_PINS[i], LOW);
  }
  runState.running = false;
  runState.pump = -1;
  runState.stopAt = 0;
  runState.ml = 0;
  runState.reason[0] = '\0';
  // Reset prime start time so that future primes start afresh
  primeStartTime = 0;

  if (wasRunning && stoppedPump >= 0) {
    serialLogf("STOP: pump %d (%s), reason=%s", stoppedPump + 1, pumps[stoppedPump].name, stoppedReason);
  } else {
    serialLogf("STOP: all pumps already idle");
  }
}

/*
 * Start a pump to dispense a specified volume (ml).  The pump will
 * run for a duration calculated from the calibration constant
 * (mlPerSec).  Returns true on success, false if a pump is already
 * running, the pump index is invalid or the mlPerSec calibration is
 * too low.  The reason string should be a short identifier used in
 * the log.
 */
bool startPumpMl(int pumpIndex, float ml, const char *reason) {
  if (pumpIndex < 0 || pumpIndex >= PUMP_COUNT) {
    serialLogf("DOSE rejected: invalid pump index %d", pumpIndex);
    return false;
  }
  if (runState.running) {
    serialLogf("DOSE rejected: pump %d is already running (%s)", runState.pump + 1, runState.reason);
    return false;
  }
  if (ml < MIN_DOSE_ML || ml > MAX_DOSE_ML) {
    serialLogf("DOSE rejected: pump %d invalid volume %.3f ml", pumpIndex + 1, ml);
    return false;
  }
  float rate = pumps[pumpIndex].mlPerSec;
  if (rate < 0.01f) {
    serialLogf("DOSE rejected: pump %d calibration too low (%.4f ml/sec)", pumpIndex + 1, rate);
    return false;
  }
  unsigned long durationMs = (unsigned long)((ml / rate) * 1000.0f);
  // Cap maximum run time to avoid runaway (2 minutes = 120000ms)
  if (durationMs > 120000UL) {
    serialLogf("DOSE rejected: pump %d duration too long (%lu ms)", pumpIndex + 1, durationMs);
    return false;
  }
  runState.running = true;
  runState.pump = pumpIndex;
  runState.stopAt = millis() + durationMs;
  runState.ml = ml;
  copyCString(runState.reason, sizeof(runState.reason), reason);
  // Start pump
  digitalWrite(PUMP_PINS[pumpIndex], HIGH);
  // Add log entry now (we know the intended dose)
  addLog(pumpIndex, ml, reason);
  serialLogf("DOSE start: pump %d (%s), %.2f ml, rate %.4f ml/sec, duration %.1f sec, reason=%s",
             pumpIndex + 1, pumps[pumpIndex].name, ml, rate, durationMs / 1000.0f, reason);
  return true;
}
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
void loop() {
  // Handle web requests
  server.handleClient();
  // Update pump runner
  updatePumpRunner();
  updateStatusLed();
  // Check schedules every minute (60000ms) only in nonâ€‘setup mode
  if (!setupMode && (millis() - lastScheduleCheck >= SCHEDULE_CHECK_INTERVAL_MS)) {
    lastScheduleCheck = millis();
    checkSchedules();
  }
  // Feed watchdog periodically (each second)
  if (millis() - lastWatchdogFeed >= 1000UL) {
    lastWatchdogFeed = millis();
    esp_task_wdt_reset();
  }
}

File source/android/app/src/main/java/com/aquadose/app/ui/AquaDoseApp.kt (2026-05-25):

package com.aquadose.app.ui

import androidx.activity.compose.BackHandler
import androidx.compose.foundation.BorderStroke
import androidx.compose.foundation.layout.BoxWithConstraints
import androidx.compose.foundation.clickable
import androidx.compose.foundation.layout.Arrangement
import androidx.compose.foundation.layout.Column
import androidx.compose.foundation.layout.ColumnScope
import androidx.compose.foundation.layout.Box
import androidx.compose.foundation.layout.PaddingValues
import androidx.compose.foundation.layout.Row
import androidx.compose.foundation.layout.RowScope
import androidx.compose.foundation.layout.Spacer
import androidx.compose.foundation.layout.defaultMinSize
import androidx.compose.foundation.layout.fillMaxHeight
import androidx.compose.foundation.layout.fillMaxSize
import androidx.compose.foundation.layout.fillMaxWidth
import androidx.compose.foundation.layout.height
import androidx.compose.foundation.layout.padding
import androidx.compose.foundation.layout.size
import androidx.compose.foundation.layout.width
import androidx.compose.foundation.layout.widthIn
import androidx.compose.foundation.lazy.LazyColumn
import androidx.compose.foundation.lazy.items
import androidx.compose.foundation.lazy.itemsIndexed
import androidx.compose.foundation.shape.RoundedCornerShape
import androidx.compose.foundation.text.KeyboardOptions
import androidx.compose.material.icons.Icons
import androidx.compose.material.icons.automirrored.filled.ArrowBack
import androidx.compose.material.icons.automirrored.filled.List
import androidx.compose.material.icons.filled.Build
import androidx.compose.material.icons.filled.CheckCircle
import androidx.compose.material.icons.filled.Error
import androidx.compose.material.icons.filled.Home
import androidx.compose.material.icons.filled.Info
import androidx.compose.material.icons.filled.PlayArrow
import androidx.compose.material.icons.filled.Refresh
import androidx.compose.material.icons.filled.Save
import androidx.compose.material.icons.filled.Schedule
import androidx.compose.material.icons.filled.Settings
import androidx.compose.material.icons.filled.Stop
import androidx.compose.material.icons.filled.Warning
import androidx.compose.material3.AlertDialog
import androidx.compose.material3.AssistChip
import androidx.compose.material3.Button
import androidx.compose.material3.ButtonDefaults
import androidx.compose.material3.Card
import androidx.compose.material3.CardDefaults
import androidx.compose.material3.CircularProgressIndicator
import androidx.compose.material3.Icon
import androidx.compose.material3.MaterialTheme
import androidx.compose.material3.NavigationBar
import androidx.compose.material3.NavigationBarItem
import androidx.compose.material3.NavigationRail
import androidx.compose.material3.NavigationRailItem
import androidx.compose.material3.OutlinedButton
import androidx.compose.material3.OutlinedTextField
import androidx.compose.material3.Scaffold
import androidx.compose.material3.Surface
import androidx.compose.material3.Switch
import androidx.compose.material3.Text
import androidx.compose.material3.TextButton
import androidx.compose.material3.VerticalDivider
import androidx.compose.runtime.Composable
import androidx.compose.runtime.DisposableEffect
import androidx.compose.runtime.LaunchedEffect
import androidx.compose.runtime.collectAsState
import androidx.compose.runtime.getValue
import androidx.compose.runtime.mutableStateOf
import androidx.compose.runtime.remember
import androidx.compose.runtime.setValue
import androidx.compose.ui.Alignment
import androidx.compose.ui.Modifier
import androidx.compose.ui.graphics.Color
import androidx.compose.ui.graphics.vector.ImageVector
import androidx.compose.ui.res.stringResource
import androidx.compose.ui.text.font.FontFamily
import androidx.compose.ui.text.font.FontWeight
import androidx.compose.ui.text.input.KeyboardType
import androidx.compose.ui.text.style.TextOverflow
import androidx.compose.ui.unit.dp
import com.aquadose.api.AquaDosePump
import com.aquadose.api.AquaDoseStatus
import com.aquadose.api.AquaDoseValidation
import com.aquadose.app.R
import com.aquadose.app.ui.theme.AquaDoseTheme

private object AquaSpace {
    val xs = 4.dp
    val sm = 8.dp
    val md = 12.dp
    val lg = 16.dp
    val xl = 24.dp
}

private object AquaShape {
    val card = RoundedCornerShape(12.dp)
    val control = RoundedCornerShape(10.dp)
    val badge = RoundedCornerShape(999.dp)
}

private enum class AquaWindowWidthClass {
    Compact,
    Medium,
    Expanded,
}

private val SuccessContainer = Color(0xFFD7F2E3)
private val OnSuccessContainer = Color(0xFF103822)
private val WarningContainer = Color(0xFFFFF2CC)
private val OnWarningContainer = Color(0xFF493700)
private const val MAX_PUMP_NAME_LENGTH = 31
private const val MAX_DIRECT_CALIBRATION_RATE_ML_PER_SEC = 100.0
@Composable
fun AquaDoseApp(viewModel: MainViewModel) {
    val uiState by viewModel.uiState.collectAsState()

    DisposableEffect(viewModel) {
        viewModel.startStatusPolling()
        onDispose { viewModel.stopStatusPolling() }
    }
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

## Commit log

2026-05-25 Initial upload of AquaDose project files
    Upload the current AquaDose project files, including application source code, release artifacts, README documentation, and supporting resources.
    [AquaDose_Case.3mf]
2026-05-25 Include AquaDose wiring diagram in README
    Added wiring diagram image to README.
2026-05-25 Fix image references for AquaDose prototype photos
    Updated image references for AquaDose prototypes in README.
